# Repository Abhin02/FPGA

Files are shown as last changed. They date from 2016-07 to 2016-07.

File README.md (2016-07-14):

# FPGA Interfacing

This project is a set of all the files and documentation of the FPGA project work that was carried out in WEL Laboratory - IIT Bombay during Summer 2016.

## Aim
* To build and program a circuit that uses a CPLD controller to divide computations between two FPGA chips.
* To program Altera CPLD chip using a microcontroller which emulates the Altera USB Blaster. This would allow direct programming from Quartus II without the hassles of external hardware requirements, UrJTAG and the need to create Serial Vector files.

## Circuit Designs

We have added the Eagle files for the Krypton Board, an Altera Max V based development board that was designed earlier by WEL Laboratory. We used this board for testing and building the circuit. The files can be found under [eagle/Krypton/](eagle/Krypton/). There are two eagle files, a daughter card for housing the Max V CPLD IC and a main board for the development board peripherals, such as LEDs and switches.

The board we worked on has been designed under [eagle/main_circuit.sch](eagle/main_circuit.sch) and [eagle/main_circuit.sch](eagle/main_circuit.sch)

A detailed documentation of the project can be found in [report.pdf](report.pdf)

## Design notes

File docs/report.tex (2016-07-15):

\documentclass[11pt]{article}
\usepackage{hyperref}
\hypersetup{
    colorlinks=true,
    linkcolor=blue,
    filecolor=magenta,      
    urlcolor=cyan,
}
\usepackage{url}
%Gummi|065|=)
\title{\textbf{FPGA Interfacing}\\Wadhwani Electronics Lab - IIT Bombay}
\author{Kalpesh Krishna - 140070017\\
		Abhin Shah - 140070013}
\date{}
\begin{document}

\maketitle

\section*{Objectives}
There have been two major aims of this project and we made some progress in each of them. This document primarily describes the progress in each of the two objectives along with the list of useful tutorials and guides.

\begin{itemize}
\item The first motive is to design and develop a circuit which makes use of an Altera Max V to control and divide computations between two Altera FPGA Integrated Circuits with the aim of maximizing productivity and minimizing the cost.
\item The second motive is to program an Altera Max V using a microcontroller, which can be used with Quartus II, Altera's proprietary software to communicate with FPGAs. Having done this, we intend to make a circuit board which will have such a CPLD and a microcontroller circuit.\\
 This would effectively eliminate the need for any external dependencies, be it Altera's USB Blaster, FTDI's FT2232H, or UrJTAG.
\end{itemize}
The entire project has been hosted on Github, under \href{https://github.com/Abhin02/FPGA}{https://github.com/Abhin02/FPGA}
\pagebreak
\section*{Objective \#1}

The project is a continuation of the work by Kamal Galrani and Manmohan Mandhana, who had designed a development board for the first objective as a part of their EDL-2 project.\\ The documentation of the old project has been added in the Github repository under \href{https://github.com/Abhin02/FPGA/tree/master/docs/edl2_project.pdf}{docs/edl2\_project.pdf}.\\
The circuit data (Eagle file) for this circuit can be found in \href{https://github.com/Abhin02/FPGA/blob/master/eagle/main_circuit.sch}{main\_circuit.sch}

\section*{Progress}
This section elaborates the progress we've made in the above objective.

\section{Altera Max V}

The old project had a few Printed Circuit Boards on which we could start working immediately. \\
The first part of the circuit involved interfacing the Altera Max V integrated circuit soldered on our PCBs with the peripherals present on the Krypton Board (\href{https://github.com/Abhin02/FPGA/blob/master/eagle/Krypton/main_brd.sch}{main\_brd.sch}), primarily the USB to JTAG converter FTDI device, FT2232H.\\
The Krypton Board seemed to have a GND loop connection which was completed through the daughter card (\href{https://github.com/Abhin02/FPGA/blob/master/eagle/Krypton/daughter_brd.sch}{daughter\_brd.sch}). As we were just using the peripherals, without any daugther card, we needed to make an external connection between two disconnected GND pins on the Krypton Board to successfully generate 3.3V and 1.8V outputs.\\
Wires were taken from the daughter card slots to our CPLD chip. The four JTAG wires, 3.3V, 1.8V and GND. Our circuit had pins to host wires from JTAG and 3.3V. To power the 1.8V line, we were forced to use the connectors between our main CPLD controller circuit and FPGA daughter circuit.\\\\ Programming was carried out using UrJTAG which would burn SVF files to the CPLD via FT2232H hosted on the Krypton Board.\\
Effectively, we made our circuit play the role of the daughter board and successfully burnt a working VHDL schematic to blink an LED.\\

\section{FT2232H}
FT2232H is a multipurpose Integrated circuit that is developed by FTDI. In our case, we are using it to burn Serial Vector Files to the CPLD using UrJTAG. Hence FT2232H effectively acts like a USB to JTAG bridge. FT2232H has been used in the Krypton Board for this very purpose. The circuit we've used is identical to the Krypton Board.\\
Here is the \href{http://www.ftdichip.com/Support/Documents/DataSheets/ICs/DS_FT2232H.pdf}{datasheet}.\\\\ 
The first step involved understanding the requirements of the FT2232H circuit. Since we were emulating the Krypton design, we primarily understood the voltage requirements of the integrated circuit.\\
3.3V was supplied to the circuit using a regulator developed at WEL, which used USB's 5V as an input supply.\\
1.8V was an output of the FT2232H circuit which was used to power the 1.8V supply line to the CPLD circuit using an external connection. (This will be replaced once the buck converter is in place).\\
After having supplied correct voltages, we succeeded in programming the CPLD completely using out circuit, without any external help from the Krypton Board. This was verified using the same LED Blink VHDL program.

\section{TPS65400}
TPS65400 is the powerhouse of our circuit. It's a Texas Instruments programmable Buck Converter, which gives four output voltages which can be decided based on external resistor values and I2C programmed internal registers.\\ Here is its \href{http://www.ti.com/lit/ds/symlink/tps65400.pdf}{datasheet}.\\\\
Since we didn't have surface mount inductors, (needed for this integrated circuit), we decided to put this on hold until we procure those inductors.\\
We spent a considerable time understanding this circuit and the way it works.
Most of the design has been taken from a schematic well explained in the datasheet. The values of the resistors have been defined and need to be soldered. Since the circuit involved I$^2$C, we decided to learn about the I$^2$C protocol.

\section{I$^2$C (Learning only)}

Inter Integrated Circuit is a popular communication protocol between devices. The first steps involved understanding the protocol. We tried a few test codes on Arduino's \href{https://www.arduino.cc/en/Reference/Wire}{Wire} library, and were successful in carry out communications between a Master Arduino and a Slave Arduino. The project files used are under ``Master Reader" and ``Master Writer" on \href{https://github.com/Abhin02/FPGA/tree/master/src/Arduino/}{Github}.\\

\section{CDCE925}
CDCE925 is a clock synthesizer integrated circuit developed by Texas Instruments which is used to amplify the frequencies of an input clock connection. As input, we've attached an input XTAL 27 MHz crystal. The output clocks have been used at different parts of the circuit as per the requirement.\\ Here is the \href{http://www.ti.com.cn/cn/lit/ds/symlink/cdce925.pdf}{datasheet}.\\
Our circuit has two special pins allotted specifically for I$^2$C communication with CDCE925 and TPS65400. CDCE925 heavily relies on I$^2$C and is locked by default. To program this circuit, we used Arduino's Wire library. We had an option to write our specification in VHDL, but we voted against it.\\\\
Since Arduino outputs 5V by default, we used a MOSFET based Logic level converter, (\href{www.rhydolabz.com/interfacing-modules-c-80/logic-level-converter-4-channel-p-1045.html}{details}) to step down the voltage to the CDCE925 compatible 3.3 Volts. Connections were straight forward, with a high impedance assigned to the Altera Max V pins connected to the I$^2$C pins of the CDCE925 (via VHDL), I$^2$C wires going from the Arduino to our I$^2$C pins via the voltage converter, and voltage lines powered up through FT2232H and the USB.\\\\
We started by running an I$^2$C identifier code in Arduino, to find our device. This code is from the \href{http://playground.arduino.cc/Main/I2cScanner}{Arduino Playground}.\\
Due to an excellent documentation given by Texas Instruments, we were successful in executing a ``Block Read" and ``Block Write" I$^2$C protocol and we could successfully read and write to the registers in CDCE925.\\
To permanently store data, this had to be written to the EEPROM register and CDCE925 has a specific procedure to write a value to EEPROM.\\\\
Unfortunately, we were unable to produce a clock output from the integrated circuit after unlocking it. We suspect a bad input circuit, or a particular faulty connection in our circuit which has damaged the IC. We hope to test this chip further in a breakout board, or  buy Texas Instrument's circuit to test CDCE925.

\section*{Future Work}
This project has a lot of components and will take substantial time to complete. We still need to work on the following:
\begin{itemize}
\item Figure out the mistakes in the CDCE925 circuit.
\item Solder, program and test TPS65400, the buck converter.
\item Solder and test the individual FPGAs on the daughter card.
\item Write a VHDL specification to control the two FPGAs using the Altera CPLD controller.
\item Make use of the Audio / Video components on the circuit board to develop a useful application of the project.
\item (Optional) Add Ethernet connectivity using Silicon Devices Ethernet controller present on our circuit board.
\item (Optional) Make use of the Flash memory on the circuit board.
\end{itemize}
\pagebreak
\section*{Objective \#2}
This is the part of the project where we hoped to use a microcontroller to program the CPLD circuit on our board. This has been done by Xilinx for their FPGAs and we hope to emulate a USB Blaster code in a microcontroller and successfully program the FPGA.
\section*{Progress}
We have tried to achieve this using two microcontrollers and have had limited success. We will describe our endeavours with each of them.
\section*{Arduino}
We found a library on Github, which uses an Arduino to burn XSVF files onto a any CPLD or FPGA. The library included an Arduino sketch to burn the XSVF player to Arduino, and external Python scripts which use \textsl{pyusb} to send those XSVF files to Arduino which sends them to a CPLD's JTAG pins.\\
This library can be found on Github, at \href{https://github.com/mrjimenez/JTAG}{https://github.com/mrjimenez/JTAG}.\\\\
This library did not work successfully with an Arduino Leonardo connected to our working CPLD circuit through JTAG wires. We suspect this is because the library is very specific to XSVF files and our CPLD will not support this file format.
\section*{Raspberry Pi}
We spent considerable time understanding and installing Raspberry Pi, since it was our first time with this magical device. Once this was setup, we started off by installing OpenOCD, a library which has JTAG programming support for a number of microcontrollers.\\
Unfortunately, due to the lack of literature online for Altera CPLDs with OpenOCD, we could not use this.\\We then installed UrJTAG on the Raspberry Pi and succeeded in communicating with the Altera CPLD chip with the GPIO pins acting as JTAG pins. The tutorial followed to achieve this is \href{https://saturn.ffzg.hr/rot13/index.cgi?action=display_html;page_name=urjtag}{here}.\\

\end{document}

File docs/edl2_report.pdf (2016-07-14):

Indian Institute of Technology,

Bombay

B.Tech Technical Project

Department of Electrical Engineering

# Low cost FPGA development

# Board

### Author:

### Kamal Galrani

### Manmohan Mandhana

### Guide:

### Prof. Joseph John

### Prof. Dipankar

### Prof. Shankar

### Balachandran

### December 9, 2015

Abstract

This project aims at designing a low cost FPGA development board which would used to run complex algorithm using partial reconfiguration on a collection of low density FPGAs (Field Programmable Gate Array) which are controlled by a CPLD (Complex Programmable Logic Device). The completed project will be able to take data over ethernet, process it and transmit it back over ethernet. High complexity architectures which take up enormous amount of resources will be broke down into smaller sections which can be uploaded on the low density FPGAs. The real time programming of the FPGAs will be handled by the CPLD. By breaking the complex algorithm into chunks we can perform the computation on our board which otherwise will require the costly high density FPGAs.

## 1 Introduction

A Field Programmable Gate Array or FPGA is an integrated circuit that could contain millions of logic gates that can be electrically configured to perform a certain task. The very basic nature of FPGAs allows it to be more flexible than most micro-controllers. FPGAs are capable of performing parallel processing. Partial re-configuration facilitates the user to re-program only a part of FPGA. This feature has many functionalities as it allows the FPGA to be configured partially and dynamically. But partially Reconfigurable FPGAs are extremely costly and the partial re-configuration functionality is not available in the low end FPGAs. Although, the low end FPGAs do have complete re-configuration functionality using parallel data transfer which makes it very fast. Exploiting the low cost and fast reconfiguration of low end FPGAs we are trying to make a development board which will allow the user to run larger programs on smaller FPGA. The larger program will be broken into smaller pieces which can run on the smaller FPGA. And using a controller CPLD we will re-configure the FPGAs in real time to perform the next functionality. This way we are able to mimic a larger FPGA with partial reconfiguration functionality in relatively low cost.

1

## 2 Technical Background

FPGA can be configured in a number of ways. For the reconfigurability, the configuration should be fast. Altera FPGAs can be configured via JTAG, Passive Serial, Active Serial, Fast Passive Parallel and Active Parallel. Passive schemes require an external host controller whereas active schemes read a memory by themselves. Among these schemes FPP is the fastest as it allows 8-bit parallel programming at 133MHz for Cyclone IV device. This means 3ms of configuration time if we have a fast enough memory. We chose a 16bit parallel flash for our purpose. It allows for 6ms configuration time. Faster memories are expensive so we made a compromise with the timing. Even at 6ms it allows for 5 stages in a 30fps pipeline. Each stage will have a maximum time limit on execution as 6ms and maximum resource limit as 15k logic elements.

### 2.1 Block Diagram

The development board is broken down into two main components :

- Main mother-board

– This Board is where all the controlling and interfacing components are placed.
– It contains all the peripherals interfacing chips such as Ethernet, Audio, Video, JTAG along with the Master CPLD and the power circuitry
- Daughter board

– This Board is where the core computation occurs
– This board contains both the FPGAs and the SRAM memory chip

The block diagram of the board including the daughter board is shown in the image below. The connector between the daughter board and the Main mother-board is a SODIMM DDR3 Connector which is generally used for connecting DDR3 RAM. As the connector supports high speed data transfer it is suitable for our use case.
We have also incorporated an Audio ADC ic and a Video decoder ic which are connected directly to the FPGAs and thus can be used to provide direct audio and video input data to the FPGA

2

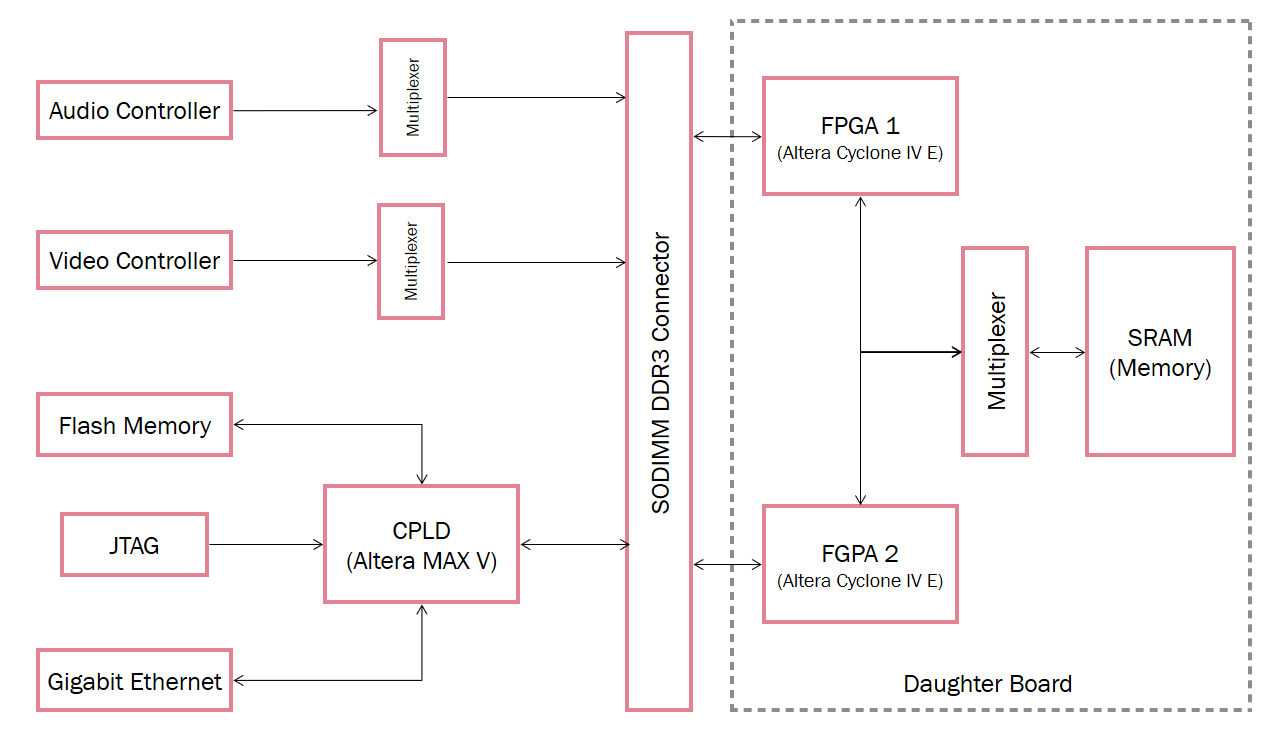
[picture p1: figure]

Figure 1: Block Diagram of Development Board

## 3 Project Implementation

### 3.1 Main mother-board

The main mother-board consists of the various interfacing peripherals and the Master CPLD. In this section we will explain the use of all the components on this board.

### 3.1.1 Master CPLD (Altera Max V)

The Master CPLD is used to configure the FPGAs on the daughter board in real time. The configuration files to be uploaded on the FPGAs are received by the Max V via Ethernet and are stored in the flash memory. The Max V also acts as a middle man between the FPGAs and the ethernet interface. The programming of the Max V is done using the JTAG interface via the on board FT2232(multi-purpose UART/FIFO controllers).

3

### 3.1.2 Gigabit Ethernet

The Gigabit ethernet is used as the main medium of data transfer between the development board and the user. We are using the ethernet controller IC called CP2200 by Silicon Labs which has a 8-bit parallel hosting interface providing upto 30 Mbps data transfer rate. The ethernet controller IC is connector the ethernet port on one end and the Max V on the other end. Ethernet is used in this development board to transfer the configuration files to Max V and to transfer the data to be processed by the FPGAs. All the data to the FPGAs is sent via the Max V CPLD.

### 3.1.3 JTAG Interface

To configure the Max V it requires a JTAG connection. For this purpose we have placed a multi-purpose USB controller (FT2232) which can be used to configure Max V using JTAG via a USB port. The same mechanism is used on the Krypton Board developed by WEL.

### 3.1.4 Flash Memory

The configuration files for the Cyclone IV E FPGAs are 3000 Mbits in size. Therefore a flash memory is connected to the Max V so that it can access the configuration files whenever it needs to reprogram the FPGAs. Flash memory usually have a slow write period but a fast read period. In our application we will write the configuration files in the flash at the start of the program and then during configuration we only need to read the data from the flash which helps in maintaining the configuration speed.
The Flash memory we are using is the SST39VF1602C by Microchip. This is a 16Mbits parallel flash memory with a 16bit data width. There is another flash by Microchip which has the same pinmap but it has 64Mbits size and thus anyone of these two can be used on the mother-board.

### 3.1.5 Power Circuitry

For the input power circuitry of the board we have used the TPS65400 by Texas Instruments which is a I2C controller Power Management unit with flexible input voltage from 4.5V - 18V. We are taking three outputs from this IC of 3.3V, 1.8V and 1.2V. The TPS65400 has 95% efficiency for each switching regulator.

4

### 3.1.6 Audio Controller

The mother-board contains a ADAU1977 by Analog Devices, which is a ADC usually used for audio applications. This ic is connected to both the FPGAs via a multiplexer and thus can be used to take input audio data to either of the FPGAs. We have provided a RCA input port for the audio in signal.

### 3.1.7 Video Controller

The mother-board also contains a ADV7180 by Analog Devices, which is a Video decoder chip. This ic is connected to both the FPGAs via a multiplexer and thus can be used to provide input analog video data to be processed data to either of the FPGAs. We have also provided a RCA input port for the analog video in signal.

### 3.1.8 SODIMM DDR3 Connector

As there many high speed connections between the mother-board and the daughter board, we have used a SODIMM DDR3 Connector by TE for connecting the daughter board.

### 3.2 Daughter Board

### 3.2.1 FPGAs (Cyclone IV E)

The FPGAs are the core computing units in this project. We have used the EP4CE15F17C8N by Altera which has 15,408 Logic Elements. The 15,000 logic elements helps to make the program chunks sufficiently large enough to contain a reasonable section of the program. We have used the FBGA-256 package which allows us to use the Fast Passive Parallel (FPP) mode of configuration for the FPGAs. The two FPGAs share all the resources via a multiplexer which is controlled by the Max V. Thus any of the FPGAs can access the audio, video and the SRAM without overloading the other FPGA’s pins.

### 3.2.2 SRAM

The FPGAs cannot store large data as they have limited number of logic elements and no inbuilt memory unit. For this purpose we have connected an 4Mbit (128K x 36) SRAM CY7C1347G by Cypress via multiplexers. This

5

SRAM can provide output at 250MHz and thus is useful for the FPGAs while performing fast computations. The 36bit wide data line helps in increasing the data bandwidth between the FPGA and the SRAM.

## 4 PCB Designs

Below are the PCB design that we made for the Main mother-board and the Daughter Board

### 4.1 Main mother-board PCB

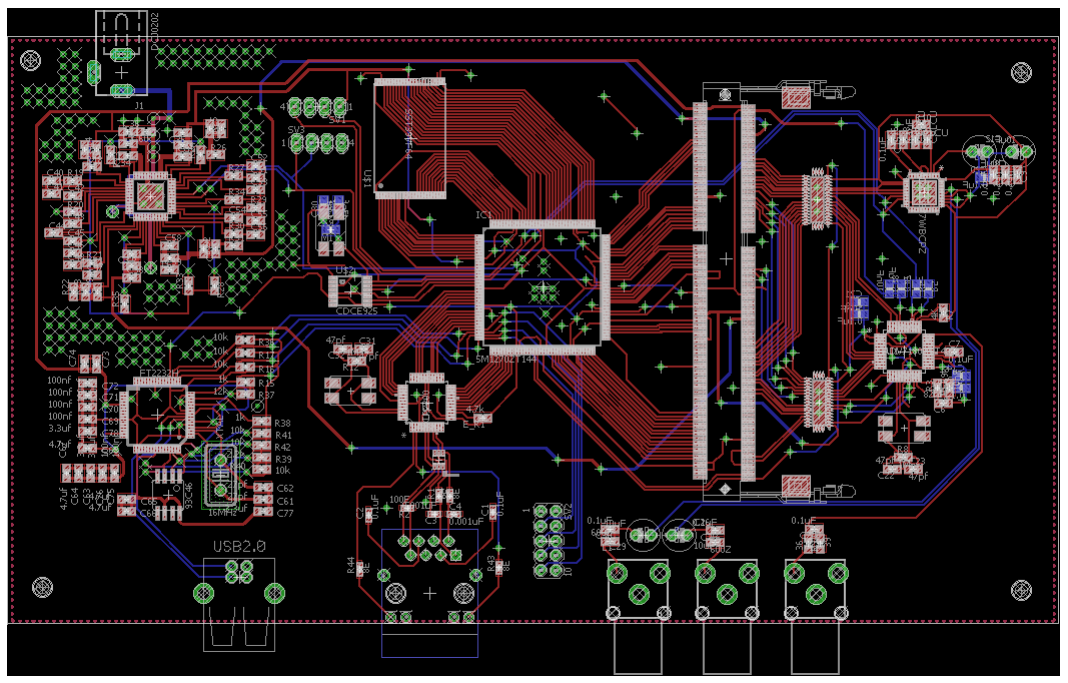
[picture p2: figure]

Figure 2: PCB layout of the motherboard

6

### 4.2 Daughter board PCB

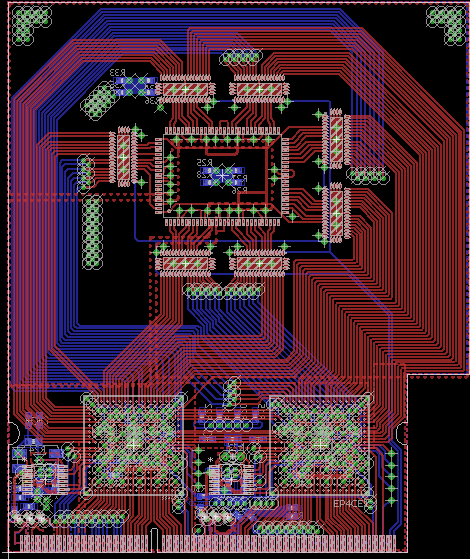
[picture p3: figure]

Figure 3: PCB layout of the Daughter Board

7

## 5 Work Done

We have completed the following work till now :

- Completed the PCB designs of both the daughter and the mother board along with acquiring all the components required for both the boards
- Sent over both the PCB files to PCB power for printing of which we have only received one board till now (main mother board)
- Written VHDL test programs for

– Flash Controller
– Reconfiguration with Max V – SRAM controller
– UART driver
– I2C driver
- Soldered the components on the Main Mother Board and the Max V was working on the board along with the PLL circuit. But due to some issue currently we are not able to program the Max V.

## 6 Work to be done

We have to complete the following work :

- Acquire the daughter board from PCB Power
- Debug the current mother board for the problem
- Solder and test all the components on the Daughter Board
- Use the test programs written for reconfiguration with both the boards connected together

## 7 References

1. Altera’s Documentation for Cyclone-IV (http://wl.altera.com/literature/lit-cyclone-iv.jsp)
2. Altera’s Documentation for MAX-V (https://www.altera.com/products/cpld/max-series/max-v/support.html)

8

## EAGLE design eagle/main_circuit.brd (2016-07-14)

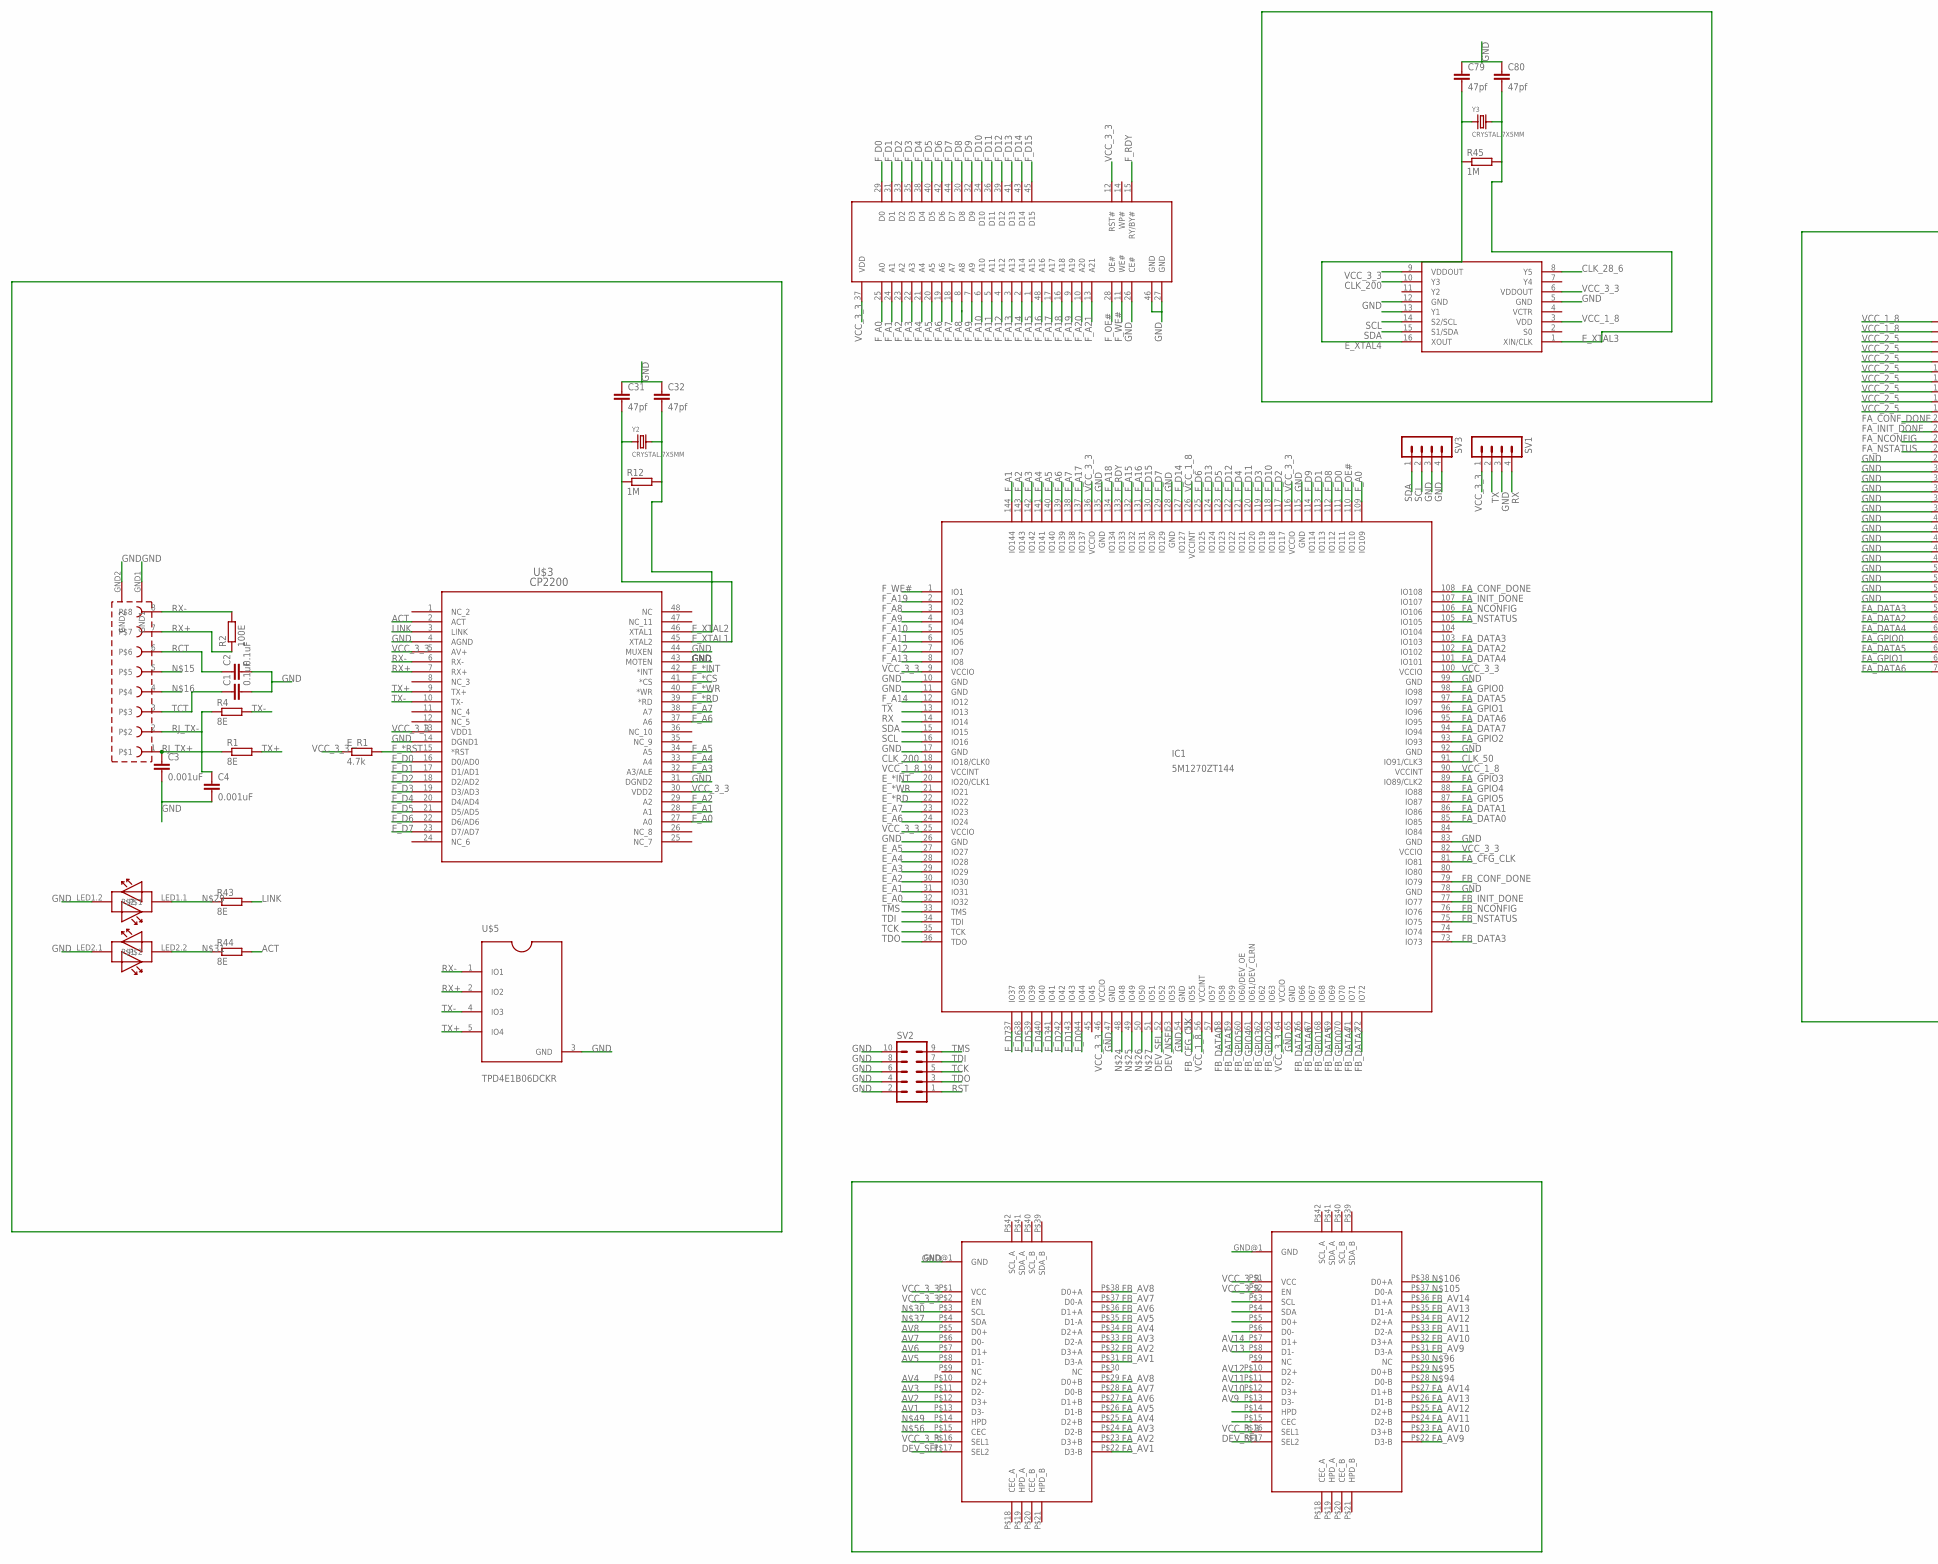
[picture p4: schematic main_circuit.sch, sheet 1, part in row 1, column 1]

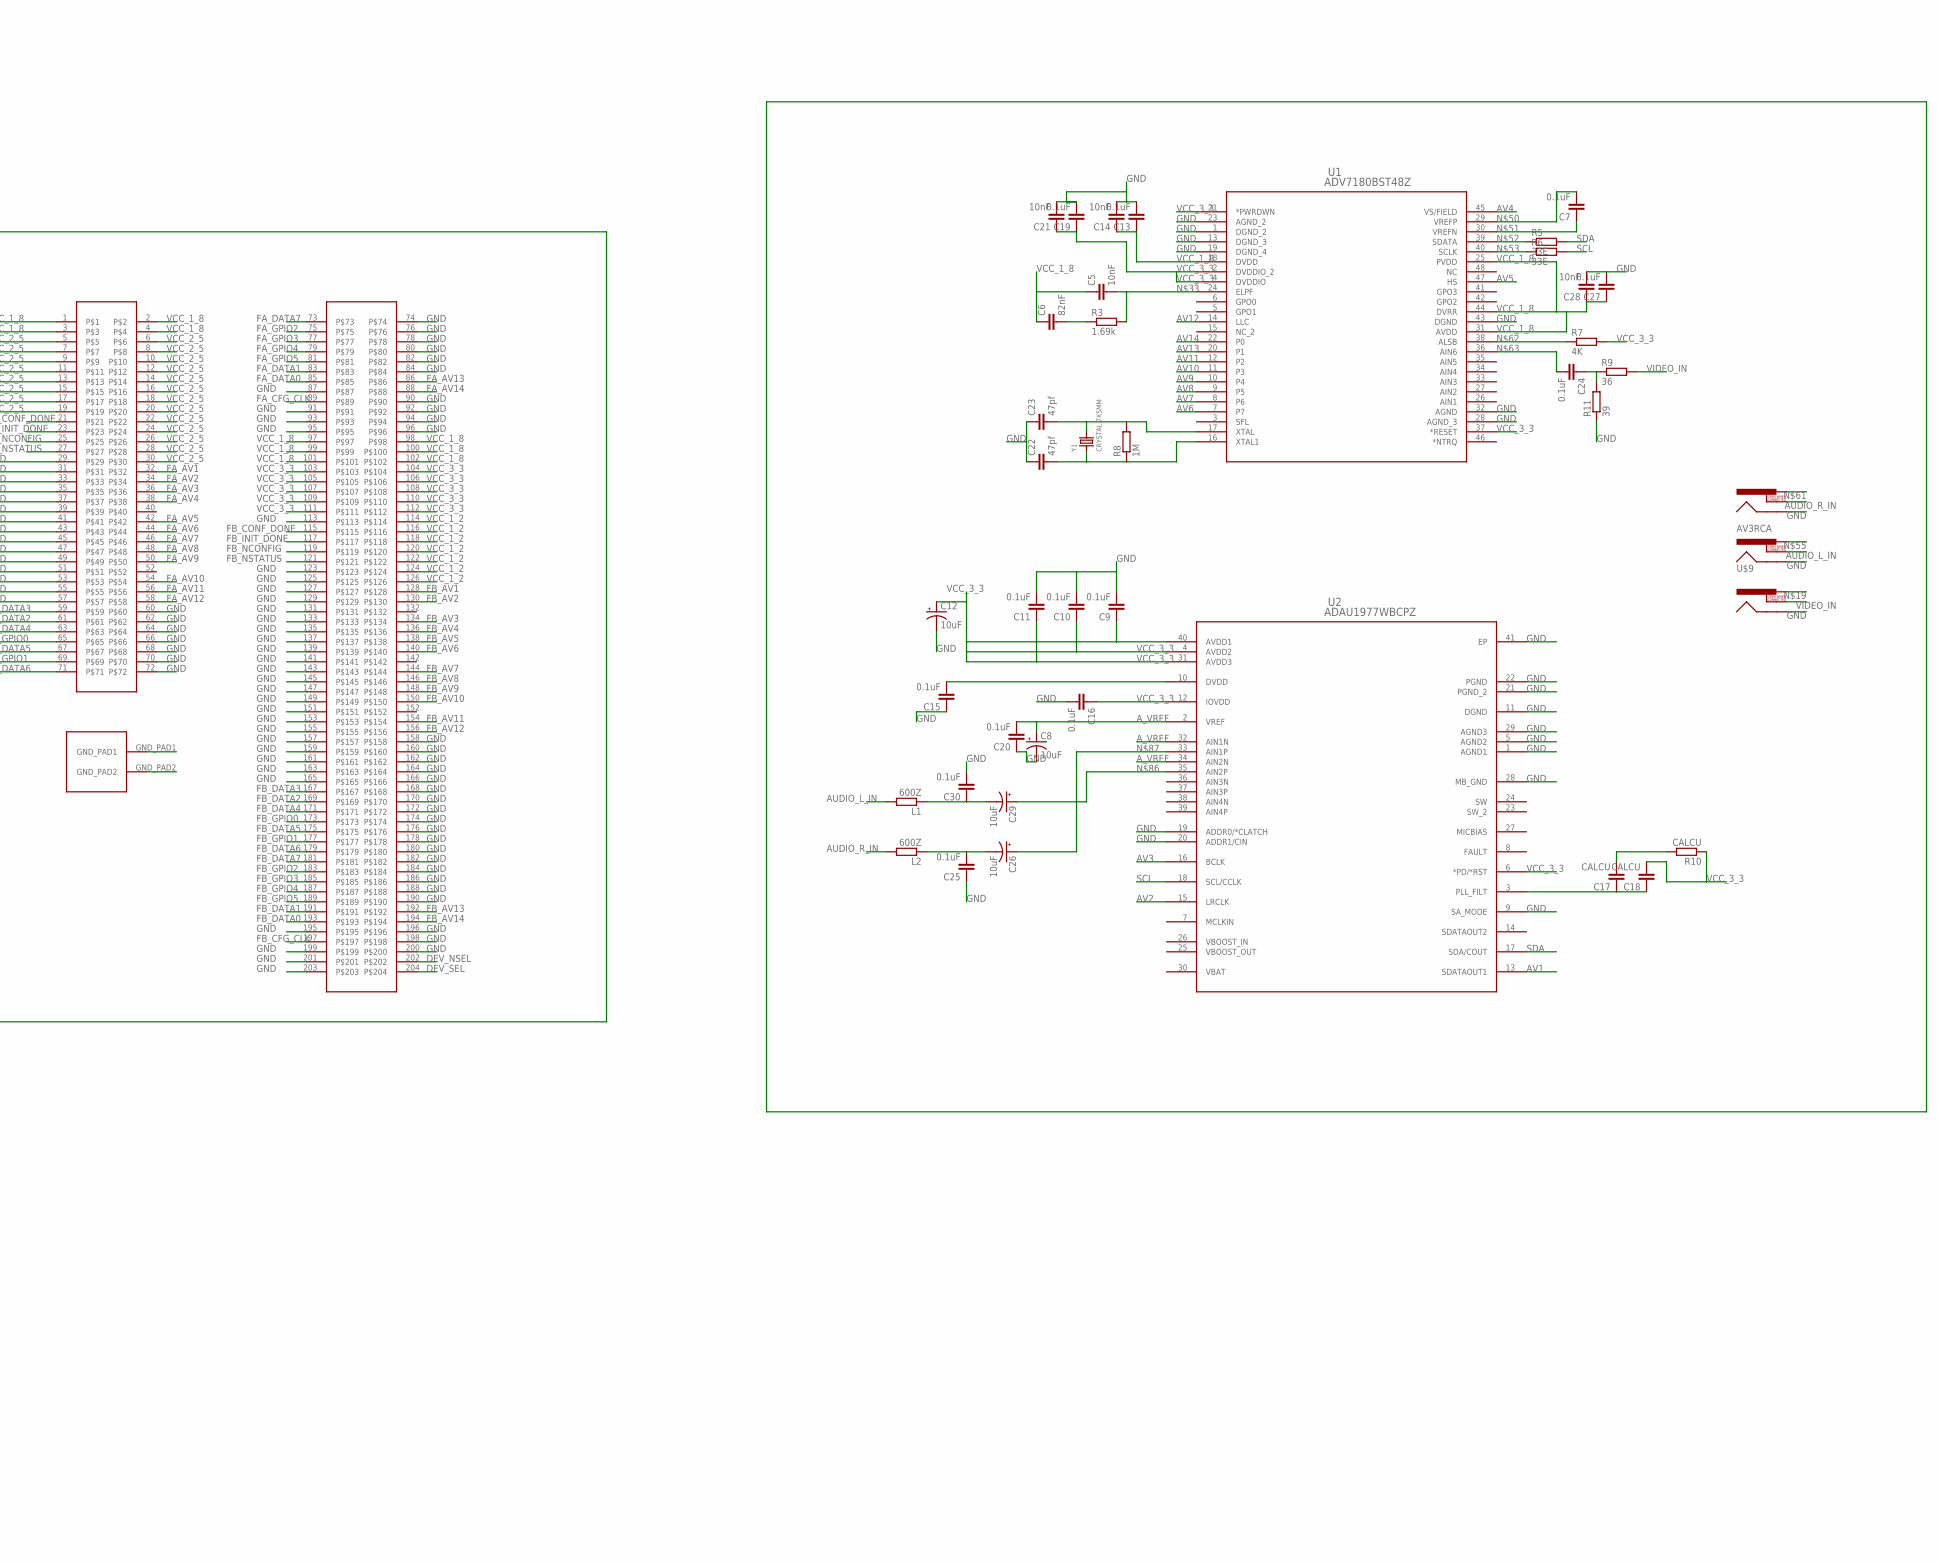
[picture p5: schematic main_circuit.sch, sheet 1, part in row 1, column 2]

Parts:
C1, C2: 0.1uF; C0402
C3, C4: 0.001uF; C0402
C5, C14, C21, C28: 10nF; C0603
C6: 82nF; C0603
C7, C9, C10, C11, C13, C15, C16, C19, C20, C24, C25, C27, C30: 0.1uF; C0603
C8, C12, C26, C29: 10uF; E2,5-6E
C17, C18: CALCU; C0603
C22, C23, C31, C32, C79, C80: 47pf; C0603
E_R1: 4.7k; R0603
GND: TS3DV642; R-PWQFN-N42
IC1: 5M1270ZT144; TQFP144
L1, L2: 600Z; R0603
R1, R4, R43, R44: 8E; R0402
R2: 100E; R0402
R3: 1.69k; R0603
R5, R6: 33E; R0603
R7: 4K; R0603
R8, R12, R45: 1M; R0603
R9: 36; R0603
R10: CALCU; R0603
R11: 39; R0603
SV1, SV3: MA04-1
SV2: MA05-2
U1: ADV7180BST48Z; ST_48
U2: ADAU1977WBCPZ; CP_40_14
U$1: SST39VF64; TSOP48
U$2: CDCE925; R-PDSO-G16
U$3: CP2200; QFP48-7X7-0P5MM
U$4: SODIMM; SODIMM_DDR3_CONN
U$5: TPD4E1B06DCKR; SC70-6
U$6: MAGJACK
U$8: TS3DV642; R-PWQFN-N42
U$9: AV3RCA
Y1, Y2, Y3: CRYSTAL.7X5MM; 7X5MM

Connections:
ACT: R44.2, U$3.2 (ACT)
AUDIO_L_IN: L1.2, U$9.SWITCH
AUDIO_R_IN: L2.2, U$9.SWITCH1
AV1: GND.P$13 (D3-), U2.13 (SDATAOUT1)
AV2: GND.P$12 (D3+), U2.15 (LRCLK)
AV3: GND.P$11 (D2-), U2.16 (BCLK)
AV4: GND.P$10 (D2+), U1.45 (VS/FIELD)
AV5: GND.P$8 (D1-), U1.47 (HS)
AV6: GND.P$7 (D1+), U1.7
AV7: GND.P$6 (D0-), U1.8 (P6)
AV8: GND.P$5 (D0+), U1.9 (P5)
AV9: U1.10 (P4), U$8.P$13 (D3-)
AV10: U1.11 (P3), U$8.P$12 (D3+)
AV11: U1.12 (P2), U$8.P$11 (D2-)
AV12: U1.14 (LLC), U$8.P$10 (D2+)
AV13: U1.20 (P1), U$8.P$8 (D1-)
AV14: U1.22 (P0), U$8.P$7 (D1+)
A_VREF: C8.+, C20.2, U2.2 (VREF), U2.32 (AIN1N), U2.34 (AIN2N)
CLK_28_6: U$2.8 (Y5)
CLK_50: IC1.91 (IO91/CLK3), U$2.13 (Y1)
CLK_200: IC1.18 (IO18/CLK0), U$2.10 (Y3)
DEV_NSEL: IC1.53 (IO53), U$4.202
DEV_SEL: GND.P$17 (SEL2), IC1.52 (IO52), U$4.204, U$8.P$17 (SEL2)
E_*CS: U$3.41 (*CS)
E_*INT: IC1.20 (IO20/CLK1), U$3.42 (*INT)
E_*RD: IC1.22 (IO22), U$3.39 (*RD)
E_*RST: E_R1.2, U$3.15 (*RST)
E_*WR: IC1.21 (IO21), U$3.40 (*WR)
E_A0: IC1.32 (IO32), U$3.27 (A0)
E_A1: IC1.31 (IO31), U$3.28 (A1)
E_A2: IC1.30 (IO30), U$3.29 (A2)
E_A3: IC1.29 (IO29), U$3.32 (A3/ALE)
E_A4: IC1.28 (IO28), U$3.33 (A4)
E_A5: IC1.27 (IO27), U$3.34 (A5)
E_A6: IC1.24 (IO24), U$3.37 (A6)
E_A7: IC1.23 (IO23), U$3.38 (A7)
E_D0: IC1.44 (IO44), U$3.16 (D0/AD0)
E_D1: IC1.43 (IO43), U$3.17 (D1/AD1)
E_D2: IC1.42 (IO42), U$3.18 (D2/AD2)
E_D3: IC1.41 (IO41), U$3.19 (D3/AD3)
E_D4: IC1.40 (IO40), U$3.20 (D4/AD4)
E_D5: IC1.39 (IO39), U$3.21 (D5/AD5)
E_D6: IC1.38 (IO38), U$3.22 (D6/AD6)
E_D7: IC1.37 (IO37), U$3.23 (D7/AD7)
E_XTAL1: C31.2, R12.1, U$3.45 (XTAL2), Y2.1
E_XTAL2: C32.2, R12.2, U$3.46 (XTAL1), Y2.3 (2)
E_XTAL3: C80.2, R45.2, U$2.1 (XIN/CLK), Y3.3 (2)
E_XTAL4: C79.2, R45.1, U$2.16 (XOUT), Y3.1
FA_AV1: GND.P$22 (D3-B), U$4.32
FA_AV2: GND.P$23 (D3+B), U$4.34
FA_AV3: GND.P$24 (D2-B), U$4.36
FA_AV4: GND.P$25 (D2+B), U$4.38
FA_AV5: GND.P$26 (D1-B), U$4.42
FA_AV6: GND.P$27 (D1+B), U$4.44
FA_AV7: GND.P$28 (D0-B), U$4.46
FA_AV8: GND.P$29 (D0+B), U$4.48
FA_AV9: U$4.50, U$8.P$22 (D3-B)
FA_AV10: U$4.54, U$8.P$23 (D3+B)
FA_AV11: U$4.56, U$8.P$24 (D2-B)
FA_AV12: U$4.58, U$8.P$25 (D2+B)
FA_AV13: U$4.86, U$8.P$26 (D1-B)
FA_AV14: U$4.88, U$8.P$27 (D1+B)
FA_CFG_CLK: IC1.81 (IO81), U$4.89
FA_CONF_DONE: IC1.108 (IO108), U$4.21
FA_DATA0: IC1.85 (IO85), U$4.85
FA_DATA1: IC1.86 (IO86), U$4.83
FA_DATA2: IC1.102 (IO102), U$4.61
FA_DATA3: IC1.103 (IO103), U$4.59
FA_DATA4: IC1.101 (IO101), U$4.63
FA_DATA5: IC1.97 (IO97), U$4.67
FA_DATA6: IC1.95 (IO95), U$4.71
FA_DATA7: IC1.94 (IO94), U$4.73
FA_GPIO0: IC1.98 (IO98), U$4.65
FA_GPIO1: IC1.96 (IO96), U$4.69
FA_GPIO2: IC1.93 (IO93), U$4.75
FA_GPIO3: IC1.89 (IO89/CLK2), U$4.77
FA_GPIO4: IC1.88 (IO88), U$4.79
FA_GPIO5: IC1.87 (IO87), U$4.81
FA_INIT_DONE: IC1.107 (IO107), U$4.23
FA_NCONFIG: IC1.106 (IO106), U$4.25
FA_NSTATUS: IC1.105 (IO105), U$4.27
FB_AV1: GND.P$31 (D3-A), U$4.128
FB_AV2: GND.P$32 (D3+A), U$4.130
FB_AV3: GND.P$33 (D2-A), U$4.134
FB_AV4: GND.P$34 (D2+A), U$4.136
FB_AV5: GND.P$35 (D1-A), U$4.138
FB_AV6: GND.P$36 (D1+A), U$4.140
FB_AV7: GND.P$37 (D0-A), U$4.144
FB_AV8: GND.P$38 (D0+A), U$4.146
FB_AV9: U$4.148, U$8.P$31 (D3-A)
FB_AV10: U$4.150, U$8.P$32 (D3+A)
FB_AV11: U$4.154, U$8.P$33 (D2-A)
FB_AV12: U$4.156, U$8.P$34 (D2+A)
FB_AV13: U$4.192, U$8.P$35 (D1-A)
FB_AV14: U$4.194, U$8.P$36 (D1+A)
FB_CFG_CLK: IC1.55 (IO55), U$4.197
FB_CONF_DONE: IC1.79 (IO79), U$4.115
FB_DATA0: IC1.58 (IO58), U$4.193
FB_DATA1: IC1.59 (IO59), U$4.191
FB_DATA2: IC1.72 (IO72), U$4.169
FB_DATA3: IC1.73 (IO73), U$4.167
FB_DATA4: IC1.71 (IO71), U$4.171
FB_DATA5: IC1.69 (IO69), U$4.175
FB_DATA6: IC1.67 (IO67), U$4.179
FB_DATA7: IC1.66 (IO66), U$4.181
FB_GPIO0: IC1.70 (IO70), U$4.173
FB_GPIO1: IC1.68 (IO68), U$4.177
FB_GPIO2: IC1.63 (IO63), U$4.183
FB_GPIO3: IC1.62 (IO62), U$4.185
FB_GPIO4: IC1.61 (IO61/DEV_CLRN), U$4.187
FB_GPIO5: IC1.60 (IO60/DEV_OE), U$4.189
FB_INIT_DONE: IC1.77 (IO77), U$4.117
FB_NCONFIG: IC1.76 (IO76), U$4.119
FB_NSTATUS: IC1.75 (IO75), U$4.121
F_A0: IC1.109 (IO109), U$1.25 (A0)
F_A1: IC1.144 (IO144), U$1.24 (A1)
F_A2: IC1.143 (IO143), U$1.23 (A2)
F_A3: IC1.142 (IO142), U$1.22 (A3)
F_A4: IC1.141 (IO141), U$1.21 (A4)
F_A5: IC1.140 (IO140), U$1.20 (A5)
F_A6: IC1.139 (IO139), U$1.19 (A6)
F_A7: IC1.138 (IO138), U$1.18 (A7)
F_A8: IC1.3 (IO3), U$1.8 (A8)
F_A9: IC1.4 (IO4), U$1.7 (A9)
F_A10: IC1.5 (IO5), U$1.6 (A10)
F_A11: IC1.6 (IO6), U$1.5 (A11)
F_A12: IC1.7 (IO7), U$1.4 (A12)
F_A13: IC1.8 (IO8), U$1.3 (A13)
F_A14: IC1.12 (IO12), U$1.2 (A14)
F_A15: IC1.132 (IO132), U$1.1 (A15)
F_A16: IC1.131 (IO131), U$1.48 (A16)
F_A17: IC1.137 (IO137), U$1.17 (A17)
F_A18: IC1.134 (IO134), U$1.16 (A18)
F_A19: IC1.2 (IO2), U$1.9 (A19)
F_A20: U$1.10 (A20)
F_A21: U$1.13 (A21)
F_D0: IC1.111 (IO111), U$1.29 (D0)
F_D1: IC1.113 (IO113), U$1.31 (D1)
F_D2: IC1.117 (IO117), U$1.33 (D2)
F_D3: IC1.119 (IO119), U$1.35 (D3)
F_D4: IC1.121 (IO121), U$1.38 (D4)
F_D5: IC1.123 (IO123), U$1.40 (D5)
F_D6: IC1.125 (IO125), U$1.42 (D6)
F_D7: IC1.129 (IO129), U$1.44 (D7)
F_D8: IC1.112 (IO112), U$1.30 (D8)
F_D9: IC1.114 (IO114), U$1.32 (D9)
F_D10: IC1.118 (IO118), U$1.34 (D10)
F_D11: IC1.120 (IO120), U$1.36 (D11)
F_D12: IC1.122 (IO122), U$1.39 (D12)
F_D13: IC1.124 (IO124), U$1.41 (D13)
F_D14: IC1.127 (IO127), U$1.43 (D14)
F_D15: IC1.130 (IO130), U$1.45 (D15)
F_OE#: IC1.110 (IO110), U$1.28 (OE#)
F_RDY: IC1.133 (IO133), U$1.15 (RY/BY#)
F_WE#: IC1.1 (IO1), U$1.11 (WE#)
GND: C1.2, C2.2, C3.2, C4.2, C8.-, C9.2, C10.2, C11.2, C12.-, C13.2, C14.2, C15.1, C16.2, C19.2, C20.1, C21.2, C22.1, C23.1, C25.1, C27.2, C28.2, C30.2, C31.1, C32.1, C79.1, C80.1, GND.GND@1 (GND), IC1.10 (GND), IC1.11 (GND), IC1.17 (GND), IC1.26 (GND), IC1.47 (GND), IC1.54 (GND), IC1.65 (GND), IC1.78 (GND), IC1.83 (GND), IC1.92 (GND), IC1.99 (GND), IC1.115 (GND), IC1.128 (GND), IC1.135 (GND), R11.1, SV1.3, SV2.2, SV2.4, SV2.6, SV2.8, SV2.10, SV3.3, SV3.4, U1.1 (DGND_2), U1.13 (DGND_3), U1.19 (DGND_4), U1.23 (AGND_2), U1.28 (AGND_3), U1.32 (AGND), U1.43 (DGND), U2.1 (AGND1), U2.5 (AGND2), U2.9 (SA_MODE), U2.11 (DGND), U2.19 (ADDR0/*CLATCH), U2.20 (ADDR1/CIN), U2.21 (PGND_2), U2.22 (PGND), U2.28 (MB_GND), U2.29 (AGND3), U2.41 (EP), U$1.26 (CE#), U$1.27 (GND), U$1.46 (GND), U$2.5 (GND), U$2.12 (GND), U$3.4 (AGND), U$3.14 (DGND1), U$3.31 (DGND2), U$3.43 (MOTEN), U$3.44 (MUXEN), U$4.29, U$4.31, U$4.33, U$4.35, U$4.37, U$4.39, U$4.41, U$4.43, U$4.45, U$4.47, U$4.49, U$4.51, U$4.53, U$4.55, U$4.57, U$4.60, U$4.62, U$4.64, U$4.66, U$4.68, U$4.70, U$4.72, U$4.74, U$4.76, U$4.78, U$4.80, U$4.82, U$4.84, U$4.87, U$4.90, U$4.91, U$4.92, U$4.93, U$4.94, U$4.95, U$4.96, U$4.113, U$4.123, U$4.125, U$4.127, U$4.129, U$4.131, U$4.133, U$4.135, U$4.137, U$4.139, U$4.141, U$4.143, U$4.145, U$4.147, U$4.149, U$4.151, U$4.153, U$4.155, U$4.157, U$4.158, U$4.159, U$4.160, U$4.161, U$4.162, U$4.163, U$4.164, U$4.165, U$4.166, U$4.168, U$4.170, U$4.172, U$4.174, U$4.176, U$4.178, U$4.180, U$4.182, U$4.184, U$4.186, U$4.188, U$4.190, U$4.195, U$4.196, U$4.198, U$4.199, U$4.200, U$4.201, U$4.203, U$4.GND_PAD1, U$4.GND_PAD2, U$5.3 (GND), U$6.GND1, U$6.GND2, U$6.LED1.2, U$6.LED2.1, U$8.GND@1 (GND), U$9.SHELL, U$9.SHELL1, U$9.SHELL2; also elsewhere on the board
IO104: IC1.104 (IO104)
LINK: R43.2, U$3.3 (LINK)
unnamed: C29.-, C30.1, L1.1
unnamed: C6.2, R3.1
unnamed: C15.2, U2.10 (DVDD)
unnamed: C25.2, C26.-, L2.1
unnamed: C24.1, R9.1, R11.2
unnamed: R43.1, U$6.LED1.1
unnamed: R44.1, U$6.LED2.2
unnamed: C5.2, R3.2, U1.24 (ELPF)
unnamed: C17.2, R10.2
unnamed: C17.1, C18.1, U2.3 (PLL_FILT)
unnamed: C23.2, R8.2, U1.17 (XTAL), Y1.3 (2)
unnamed: C22.2, R8.1, U1.16 (XTAL1), Y1.1
unnamed: C7.2, U1.29 (VREFP)
unnamed: C7.1, U1.30 (VREFN)
unnamed: R5.1, U1.39 (SDATA)
unnamed: R6.1, U1.40 (SCLK)
unnamed: R7.1, U1.38 (ALSB)
unnamed: C24.2, U1.36 (AIN6)
unnamed: C29.+, U2.35 (AIN2P)
unnamed: C26.+, U2.33 (AIN1P)
RCT: C2.1, U$6.6
RJ_TX+: C3.1, R1.1, U$6.1
RJ_TX-: C4.1, R4.1, U$6.2
RST: SV2.1
RX: IC1.14 (IO14), SV1.4
RX+: R2.1, U$3.7 (RX+), U$5.2 (IO2), U$6.7
RX-: R2.2, U$3.6 (RX-), U$5.1 (IO1), U$6.8
SCL: IC1.16 (IO16), R6.2, SV3.2, U2.18 (SCL/CCLK), U$2.14 (S2/SCL); also elsewhere on the board
SDA: IC1.15 (IO15), R5.2, SV3.1, U2.17 (SDA/COUT), U$2.15 (S1/SDA); also elsewhere on the board
TCK: IC1.35 (TCK), SV2.5; also elsewhere on the board
TCT: C1.1, U$6.3
TDI: IC1.34 (TDI), SV2.7; also elsewhere on the board
TDO: IC1.36 (TDO), SV2.3; also elsewhere on the board
TMS: IC1.33 (TMS), SV2.9; also elsewhere on the board
TX: IC1.13 (IO13), SV1.2
TX+: R1.2, U$3.9 (TX+), U$5.5 (IO4)
TX-: R4.2, U$3.10 (TX-), U$5.4 (IO3)
VCC_1_2: U$4.114, U$4.116, U$4.118, U$4.120, U$4.122, U$4.124, U$4.126; also elsewhere on the board
VCC_1_8: C5.1, C6.1, C13.1, C14.1, C27.1, C28.1, IC1.19 (VCCINT), IC1.56 (VCCINT), IC1.90 (VCCINT), IC1.126 (VCCINT), U1.18 (DVDD), U1.25 (PVDD), U1.31 (AVDD), U1.44 (DVRR), U$2.3 (VDD), U$4.1, U$4.2, U$4.3, U$4.4, U$4.97, U$4.98, U$4.99, U$4.100, U$4.101, U$4.102; also elsewhere on the board
VCC_2_5: U$4.5, U$4.6, U$4.7, U$4.8, U$4.9, U$4.10, U$4.11, U$4.12, U$4.13, U$4.14, U$4.15, U$4.16, U$4.17, U$4.18, U$4.19, U$4.20, U$4.22, U$4.24, U$4.26, U$4.28, U$4.30; also elsewhere on the board
VCC_3_3: C9.1, C10.1, C11.1, C12.+, C16.1, C18.2, C19.1, C21.1, E_R1.1, GND.P$1 (VCC), GND.P$2 (EN), GND.P$16 (SEL1), IC1.9 (VCCIO), IC1.25 (VCCIO), IC1.46 (VCCIO), IC1.64 (VCCIO), IC1.82 (VCCIO), IC1.100 (VCCIO), IC1.116 (VCCIO), IC1.136 (VCCIO), R7.2, R10.1, SV1.1, U1.2 (DVDDIO_2), U1.4 (DVDDIO), U1.21 (*PWRDWN), U1.37 (*RESET), U2.4 (AVDD2), U2.6 (*PD/*RST), U2.12 (IOVDD), U2.31 (AVDD3), U2.40 (AVDD1), U$1.12 (RST#), U$1.37 (VDD), U$2.6 (VDDOUT), U$2.9 (VDDOUT), U$3.5 (AV+), U$3.13 (VDD1), U$3.30 (VDD2), U$4.103, U$4.104, U$4.105, U$4.106, U$4.107, U$4.108, U$4.109, U$4.110, U$4.111, U$4.112, U$8.P$1 (VCC), U$8.P$2 (EN), U$8.P$16 (SEL1); also elsewhere on the board
VIDEO_IN: R9.2, U$9.SWITCH2

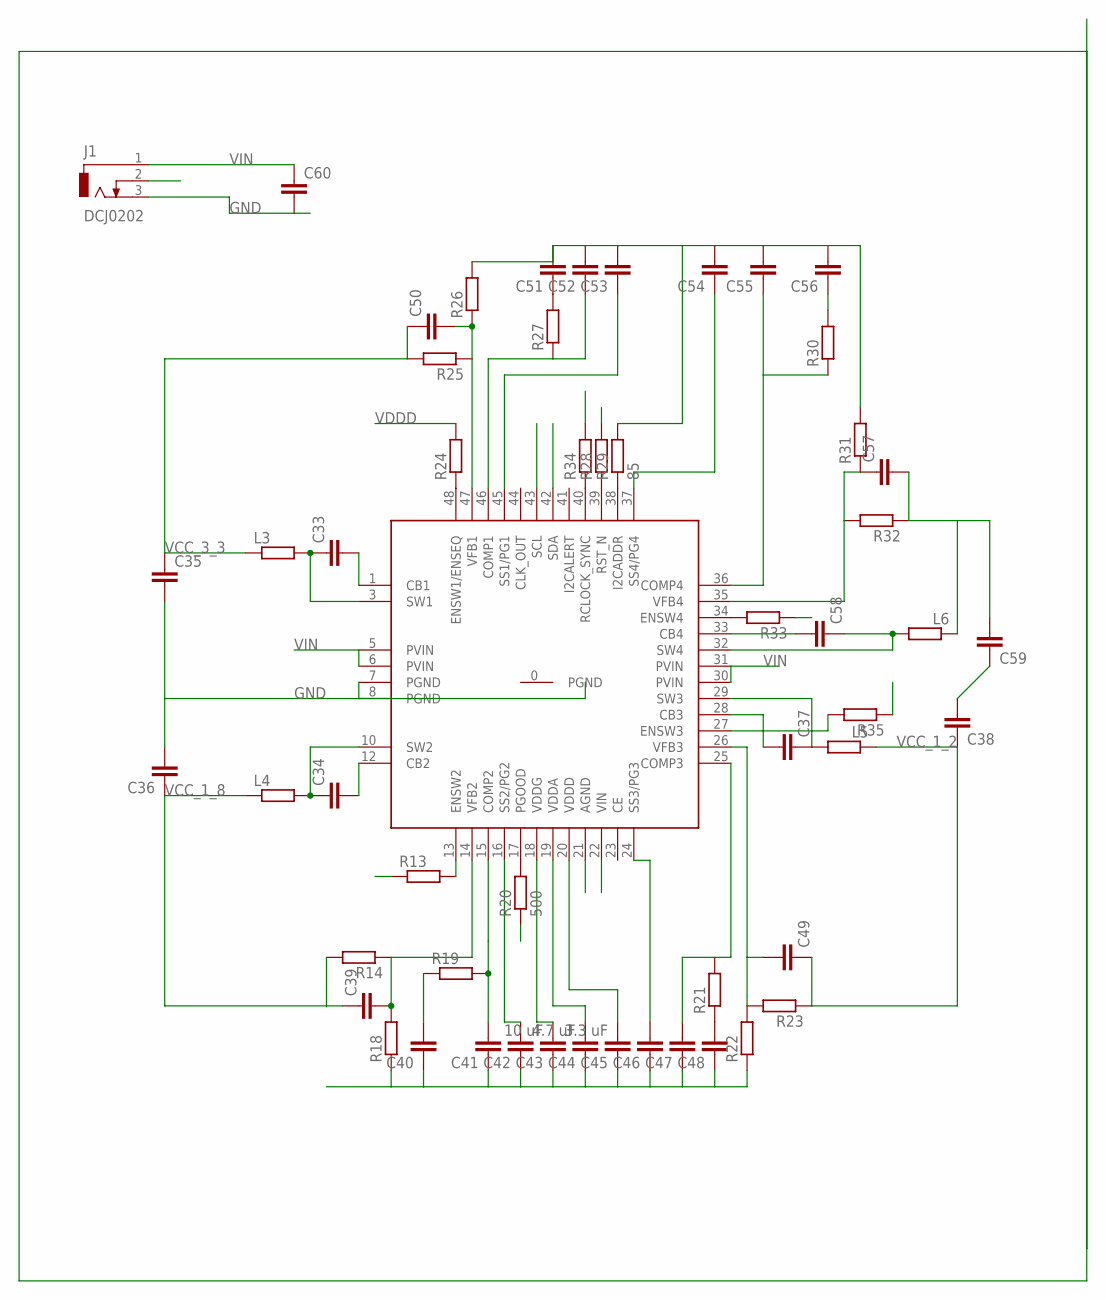
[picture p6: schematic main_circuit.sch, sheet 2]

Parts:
C33, C34, C35, C36, C37, C38, C39, C40, C41, C42, C46, C47, C48, C49, C50, C51, C52, C53, C54, C55, C56, C57, C58, C59, C60: CC0603; C0603
C43: 10 uF; C0603
C44: 4.7 uF; C0603
C45: 3.3 uF; C0603
J1: DCJ0202
L3, L4, L5, L6: RR0603; R0603
R13, R14, R18, R19, R21, R22, R23, R24, R25, R26, R27, R28, R30, R31, R32, R33, R34, R35: RR0603; R0603
R20: 500; R0603
R29: 85; R0603
U$10: TPS65400RGZR; VQFN48

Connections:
ENSW3: R35.2, U$10.27 (ENSW3)
ENSW4: R33.2, U$10.34 (ENSW4)
GND: C35.2, C36.2, C38.2, C40.1, C41.1, C42.1, C43.1, C44.1, C45.1, C46.1, C47.1, C48.1, C51.2, C52.2, C53.2, C54.2, C55.2, C56.2, C60.2, J1.3, R18.1, R22.1, R26.2, R29.2, R31.2, R34.2, U$10.7 (PGND), U$10.8 (PGND), U$10.21 (AGND); also elsewhere on the board
unnamed: C33.2, U$10.1 (CB1)
unnamed: C33.1, L3.2, U$10.3 (SW1)
unnamed: C34.1, L4.2, U$10.10 (SW2)
unnamed: C34.2, U$10.12 (CB2)
unnamed: C37.1, L5.2, U$10.29 (SW3)
unnamed: C37.2, U$10.28 (CB3)
unnamed: R13.2, U$10.13 (ENSW2)
unnamed: C39.2, R14.1, R18.2, U$10.14 (VFB2)
unnamed: C40.2, R19.1
unnamed: R20.2, U$10.17 (PGOOD)
unnamed: C41.2, R19.2, U$10.15 (COMP2)
unnamed: C43.2, U$10.18 (VDDG)
unnamed: C44.2, U$10.19 (VDDA)
unnamed: C46.2, U$10.24 (SS3/PG3)
unnamed: C42.2, U$10.16 (SS2/PG2)
unnamed: C48.2, R21.1
unnamed: C49.2, R22.2, R23.2, U$10.26 (VFB3)
unnamed: C47.2, R21.2, U$10.25 (COMP3)
unnamed: R24.1, U$10.48 (ENSW1/ENSEQ)
unnamed: C51.1, R27.2
unnamed: R29.1, U$10.38 (I2CADDR)
unnamed: C57.1, R31.1, R32.2, U$10.35 (VFB4)
unnamed: C58.1, L6.2, U$10.32 (SW4)
unnamed: C50.2, R25.1, R26.1, U$10.47 (VFB1)
unnamed: C56.1, R30.2
unnamed: C52.1, R27.1, U$10.46 (COMP1)
unnamed: C53.1, U$10.45 (SS1/PG1)
unnamed: C54.1, U$10.37 (SS4/PG4)
unnamed: C55.1, R30.1, U$10.36 (COMP4)
unnamed: C58.2, U$10.33 (CB4)
unnamed: R34.1, U$10.40 (RCLOCK_SYNC)
RST_N: R28.1, U$10.39 (RST_N)
SCL: U$10.43 (SCL); also elsewhere on the board
SDA: U$10.42 (SDA); also elsewhere on the board
VCC_1_2: C38.1, C49.1, L5.1, R23.1; also elsewhere on the board
VCC_1_8: C36.1, C39.1, L4.1, R14.2; also elsewhere on the board
VCC_2_5: C57.2, C59.2, L6.1, R32.1; also elsewhere on the board
VCC_3_3: C35.1, C50.1, L3.1, R25.2; also elsewhere on the board
VDDD: C45.2, R13.1, R20.1, R24.2, R28.2, R33.1, R35.1, U$10.20 (VDDD)
VIN: C60.1, J1.1, U$10.5 (PVIN), U$10.6 (PVIN), U$10.22 (VIN), U$10.30 (PVIN), U$10.31 (PVIN)

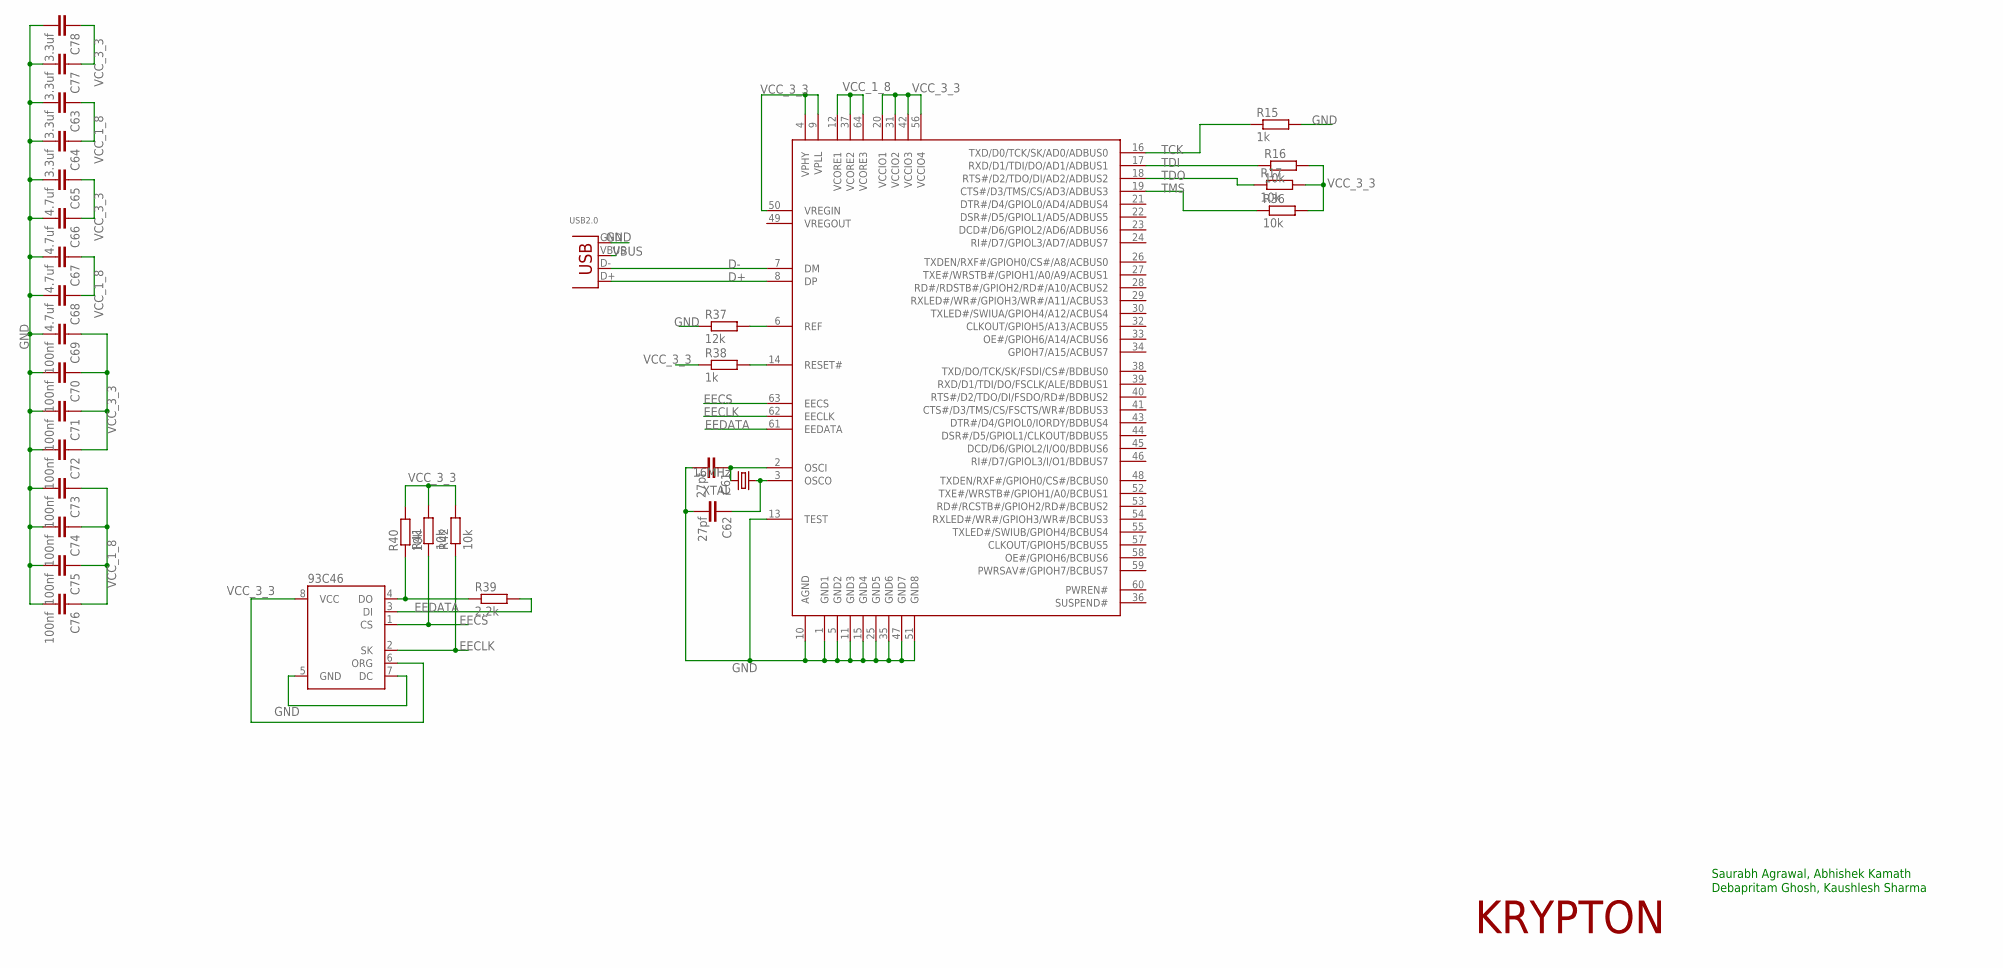
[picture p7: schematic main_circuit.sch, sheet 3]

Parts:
93C46: AT93C6; SOIC8
C61, C62: 27pf; C0603
C63, C64, C77, C78: 3.3uf; C0603
C65, C66, C67, C68: 4.7uf; C0603
C69, C70, C71, C72, C73, C74, C75, C76: 100nf; C0603
FT2232H: FT2232H; LQFP_NEW
R15, R38: 1k; R0603
R16, R17, R36, R40, R41, R42: 10k; R0603
R37: 12k; R0603
R39: 2.2k; R0603
USB2.0: USB-B-H
XTAL: 16MHz; HC18U-V

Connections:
D+: FT2232H.8 (DP), USB2.0.D+
D-: FT2232H.7 (DM), USB2.0.D-
EECLK: 93C46.2 (SK), FT2232H.62 (EECLK), R42.1
EECS: 93C46.1 (CS), FT2232H.63 (EECS), R41.1
EEDATA: 93C46.3 (DI), FT2232H.61 (EEDATA), R39.2
GND: 93C46.5 (GND), 93C46.7 (DC), C61.2, C62.2, C63.2, C64.2, C65.2, C66.2, C67.2, C68.2, C69.2, C70.2, C71.2, C72.2, C73.2, C74.2, C75.2, C76.2, C77.2, C78.2, FT2232H.1 (GND1), FT2232H.5 (GND2), FT2232H.10 (AGND), FT2232H.11 (GND3), FT2232H.13 (TEST), FT2232H.15 (GND4), FT2232H.25 (GND5), FT2232H.35 (GND6), FT2232H.47 (GND7), FT2232H.51 (GND8), R15.2, R37.1, USB2.0.GND; also elsewhere on the board
unnamed: FT2232H.6 (REF), R37.2
unnamed: FT2232H.14 (RESET#), R38.2
unnamed: 93C46.4 (DO), R39.1, R40.1
OSCI: C61.1, FT2232H.2 (OSCI), XTAL.2
OSCO: C62.1, FT2232H.3 (OSCO), XTAL.1
TCK: FT2232H.16 (TXD/D0/TCK/SK/AD0/ADBUS0), R15.1; also elsewhere on the board
TDI: FT2232H.17 (RXD/D1/TDI/DO/AD1/ADBUS1), R16.1; also elsewhere on the board
TDO: FT2232H.18 (RTS#/D2/TDO/DI/AD2/ADBUS2), R17.1; also elsewhere on the board
TMS: FT2232H.19 (CTS#/D3/TMS/CS/AD3/ADBUS3), R36.1; also elsewhere on the board
VBUS: USB2.0.VBUS
VCC_1_8: C63.1, C64.1, C67.1, C68.1, C73.1, C74.1, C75.1, C76.1, FT2232H.12 (VCORE1), FT2232H.37 (VCORE2), FT2232H.64 (VCORE3); also elsewhere on the board
VCC_3_3: 93C46.6 (ORG), 93C46.8 (VCC), C65.1, C66.1, C69.1, C70.1, C71.1, C72.1, C77.1, C78.1, FT2232H.4 (VPHY), FT2232H.9 (VPLL), FT2232H.20 (VCCIO1), FT2232H.31 (VCCIO2), FT2232H.42 (VCCIO3), FT2232H.50 (VREGIN), FT2232H.56 (VCCIO4), R16.2, R17.2, R36.2, R38.1, R40.2, R41.2, R42.2; also elsewhere on the board

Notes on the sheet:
Saurabh Agrawal, Abhishek Kamath
Debapritam Ghosh, Kaushlesh Sharma
KRYPTON

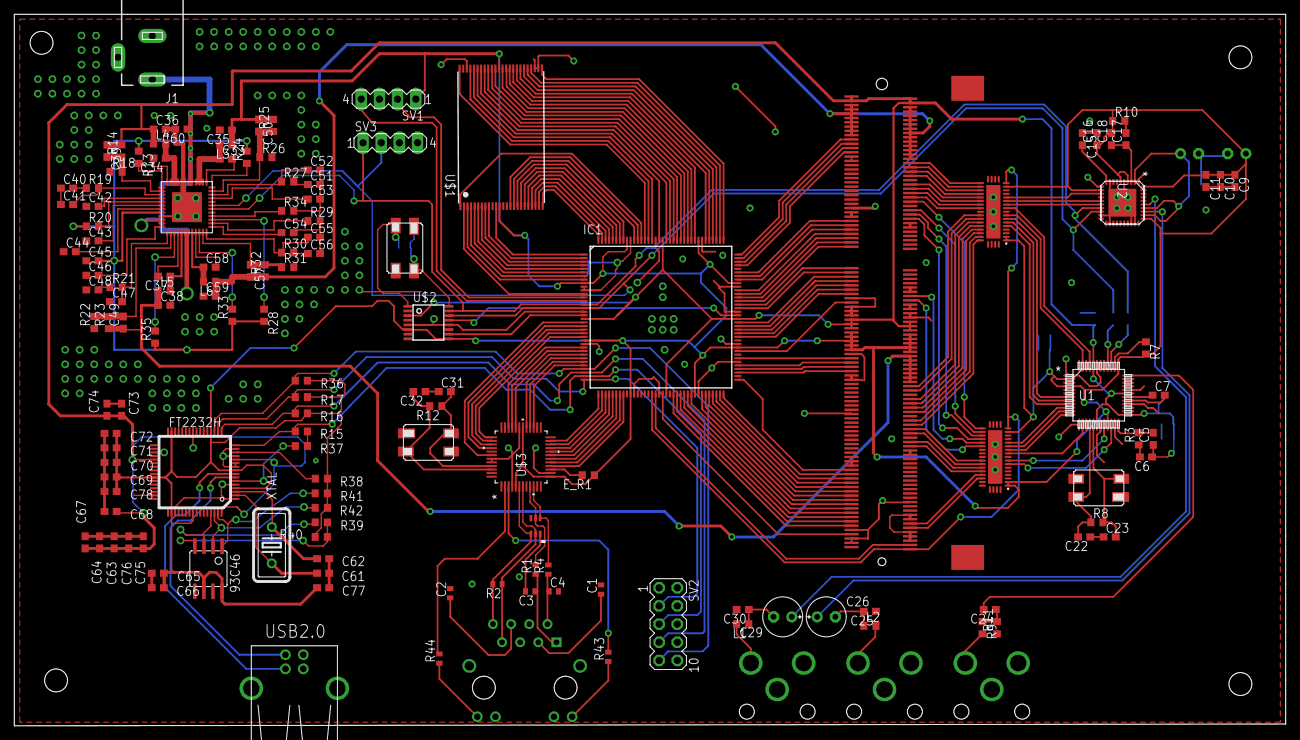
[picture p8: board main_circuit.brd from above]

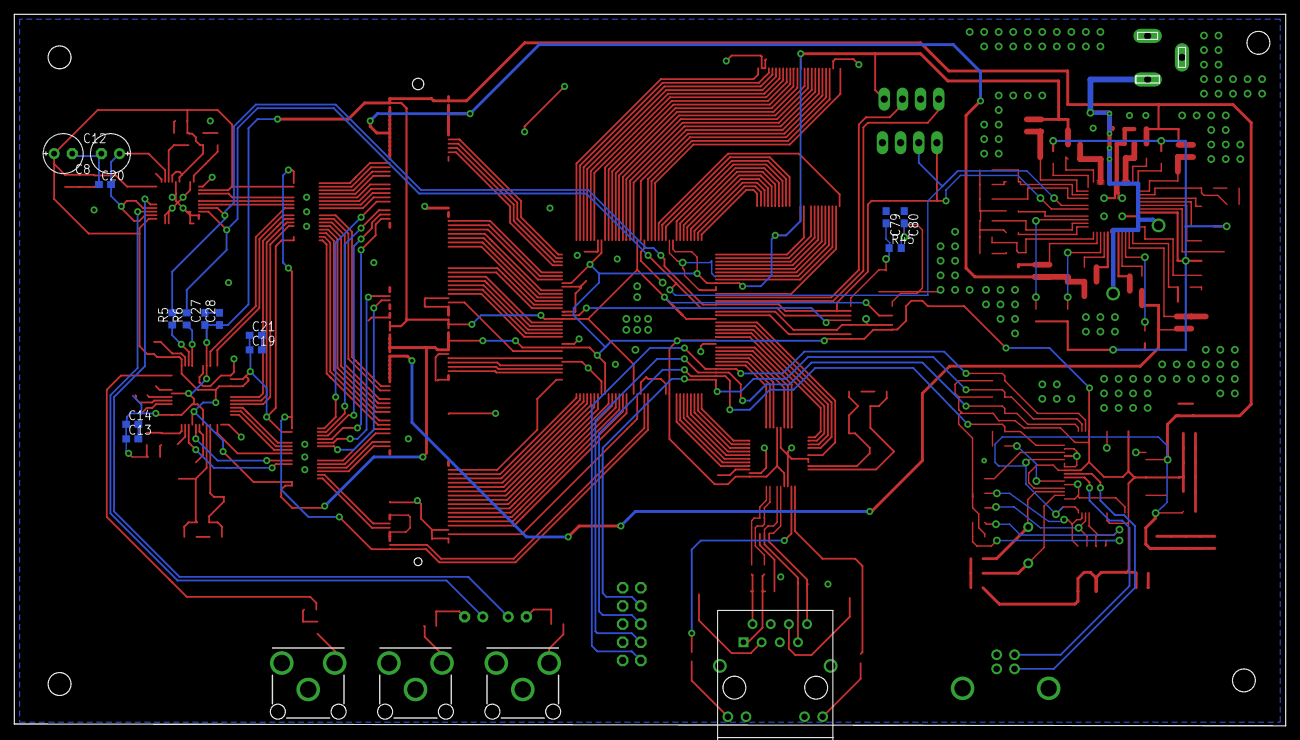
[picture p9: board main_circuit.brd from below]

Board: 2 copper layers, 177.8 x 99.5 mm, 156 parts (16 on the bottom side), 240 nets.

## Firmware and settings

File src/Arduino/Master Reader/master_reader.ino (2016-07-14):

// Wire Master Reader
// by Nicholas Zambetti <http://www.zambetti.com>

// Demonstrates use of the Wire library
// Reads data from an I2C/TWI slave device
// Refer to the "Wire Slave Sender" example for use with this

// Created 29 March 2006

// This example code is in the public domain.


#include <Wire.h>

void setup() {
  Wire.begin();        // join i2c bus (address optional for master)
  Serial.begin(9600);  // start serial for output
}

void loop() {
  Wire.requestFrom(8, 6);    // request 6 bytes from slave device #8

  while (Wire.available()) { // slave may send less than requested
    char c = Wire.read(); // receive a byte as character
    Serial.print(c);         // print the character
  }

  delay(500);
}

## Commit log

2016-07-14 Adding Arduino codes
2016-07-14 Removing temporary files and adding a .gitignore file
    [daughter_brd.brd, daughter_brd.sch, main_brd.brd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]
2016-07-14 Changing file and folder names
    [daughter_brd.brd, daughter_brd.sch, main_brd.brd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]

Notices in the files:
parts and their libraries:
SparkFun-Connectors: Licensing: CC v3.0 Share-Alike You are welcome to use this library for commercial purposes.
